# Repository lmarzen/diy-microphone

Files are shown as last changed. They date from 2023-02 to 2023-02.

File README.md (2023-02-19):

# diy-microphone

This project contributes a KiCad PCB design that implements the circuit described in the DIY Perks Microphone Project v1, https://www.youtube.com/watch?v=LoQu3XXIayc.

The PCB is designed to fit the internal form factor of the body of BM-800 XLR microphone. The BM-800 is an inexpensive microphone with a metal housing. The limited interior space of the microphone housing necessitates a dense PCB layout.

The XLR plug is replaced with a USB C female connector and a 3d printed mount is used to secure it. The SolidWorks part file and the .STL have been included as part of this repository. Additionally this 3d printable mount is used to hold the mic capsole, https://www.thingiverse.com/thing:2541735. I used a 1k reverse log potentiometer for volume control. It works and sounds great! Here are some pictures.

<p float="left">
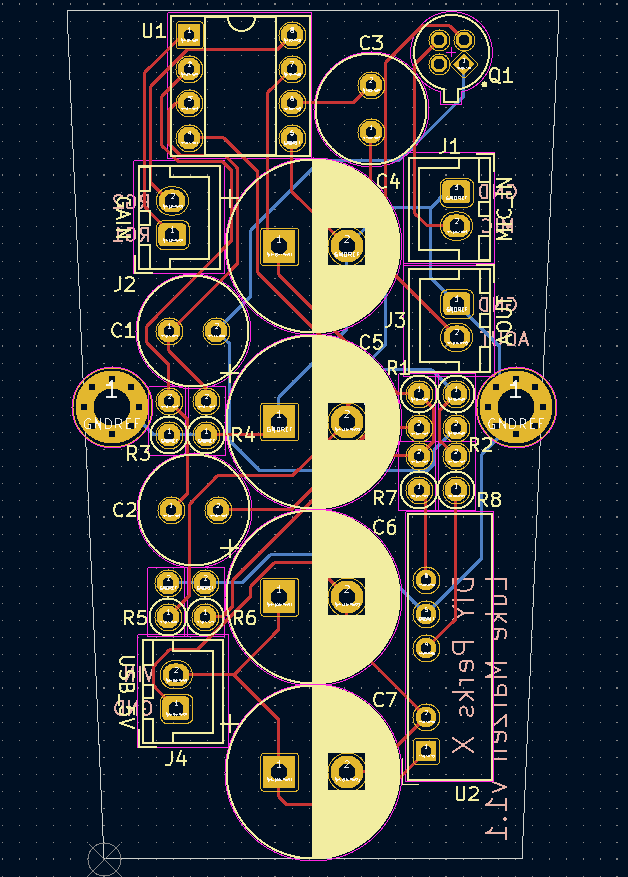
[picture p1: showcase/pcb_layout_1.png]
  
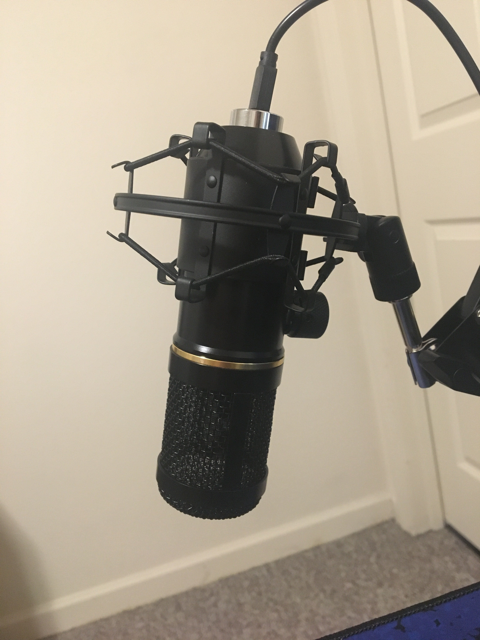
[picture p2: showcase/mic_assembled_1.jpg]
  
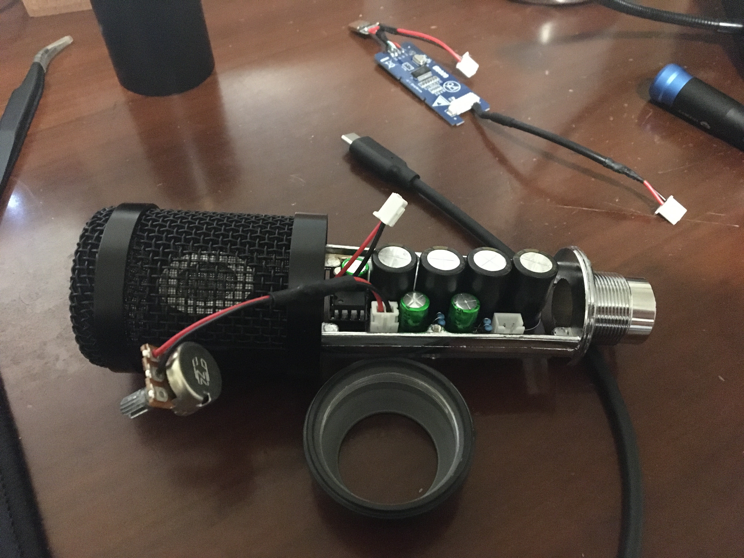
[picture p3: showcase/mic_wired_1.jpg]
  
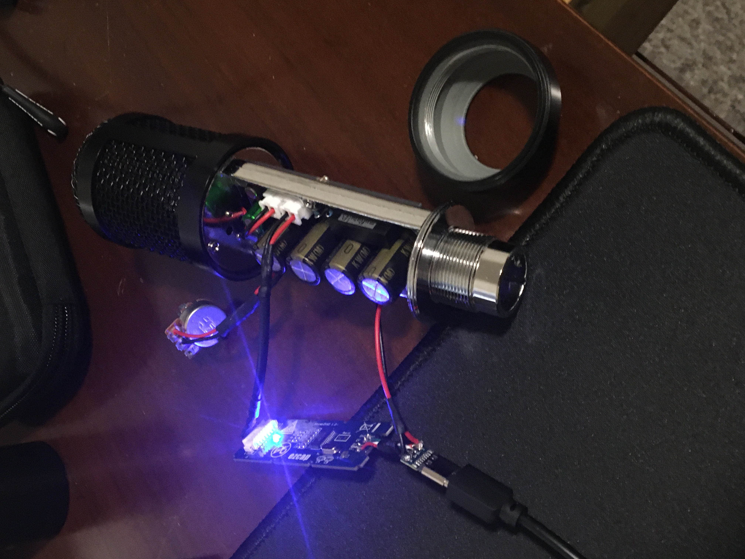
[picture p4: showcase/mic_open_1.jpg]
   
</p>

Matt (DIY Perks) has created extensive documentation for the DIY Perks Microphone Project v1 in the form of a youtube video, https://www.youtube.com/watch?v=LoQu3XXIayc. More information related to his project can be found here, https://diyperks.com/project_31_high-quality-usb-c-microphone/.

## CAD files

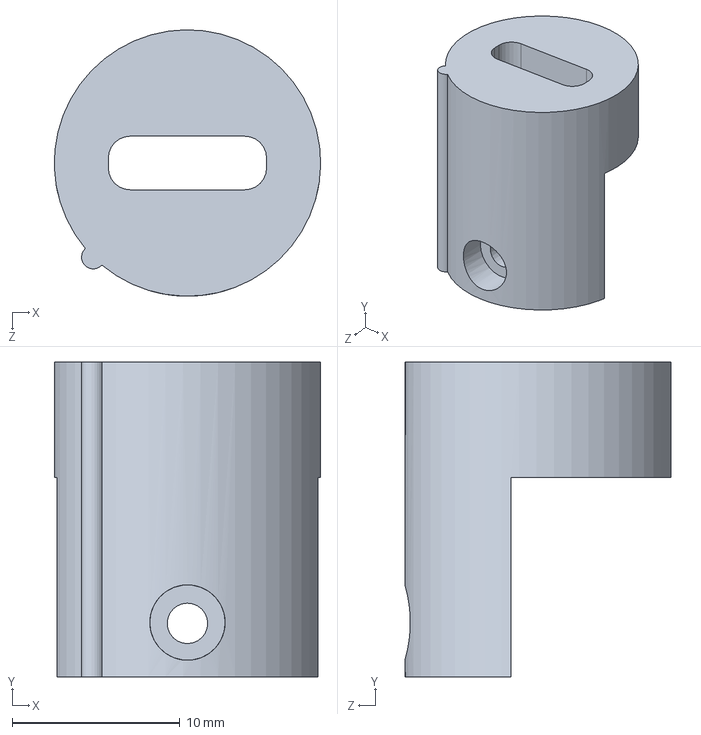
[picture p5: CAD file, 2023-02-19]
XLR_to_USB_mic.SLDPRT
15.9 x 18.8 x 15.9 mm

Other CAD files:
XLR_to_USB_mic.STL

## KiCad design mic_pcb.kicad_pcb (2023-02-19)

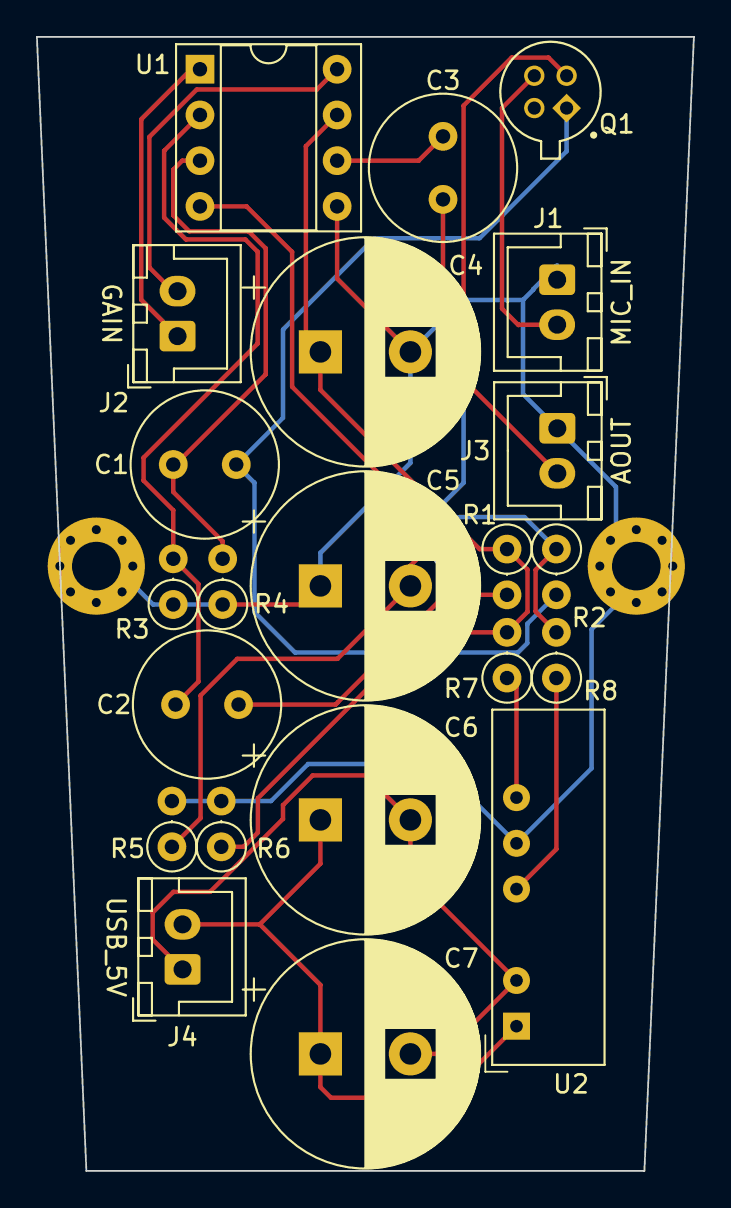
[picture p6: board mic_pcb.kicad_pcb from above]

Board: 2 copper layers, 36.5 x 63.0 mm, 22 parts (0 on the bottom side), 16 nets.

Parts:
C1, C2, C3: 22uf 35v; C_Radial_D8.0mm_H11.5mm_P3.50mm
C4, C5, C6, C7: 2200uf 16v; CP_Radial_D12.5mm_P5.00mm
J1: MIC_IN; JST_XH_B2B-XH-A_1x02_P2.50mm_Vertical
J2: GAIN; JST_XH_B2B-XH-A_1x02_P2.50mm_Vertical
J3: AUDIO_OUT; JST_XH_B2B-XH-A_1x02_P2.50mm_Vertical
J4: 5v USB; JST_XH_B2B-XH-A_1x02_P2.50mm_Vertical
Q1: 2N4416; TO127P584H533-4
R1, R2, R5, R6: 2.2k; R_Axial_DIN0207_L6.3mm_D2.5mm_P2.54mm_Vertical
R3, R4: 3.9k; R_Axial_DIN0207_L6.3mm_D2.5mm_P2.54mm_Vertical
R7, R8: 100; R_Axial_DIN0207_L6.3mm_D2.5mm_P2.54mm_Vertical
U1: THAT1512; DIP-8_W7.62mm_Socket
U2: NMA0515SC; Converter_DCDC_Murata_NMAxxxxSC_THT

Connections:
GNDREF: C4.2, C5.1, J1.1, J3.1, R3.1, R4.1, R5.2, R6.2, U1.5 (REF), U2.5 (0V)
unnamed: C1.1, R4.2, U1.3 (IN+)
unnamed: C1.2, Q1.1, R2.2
unnamed: C2.1, R3.2, U1.2 (IN-)
unnamed: C2.2, Q1.2, R1.2
unnamed: C3.1, J3.2
unnamed: C3.2, U1.6
unnamed: C4.1, R1.1, R6.1, R7.2, U1.7 (V+)
unnamed: C5.2, R2.1, R5.1, R8.2, U1.4 (V-)
unnamed: C6.1, C7.1, J4.2, U2.1 (VIN+)
unnamed: C6.2, C7.2, J4.1, U2.2 (VIN-)
unnamed: J1.2, Q1.3
unnamed: J2.1, U1.1 (RG1)
unnamed: J2.2, U1.8 (RG2)
unnamed: R7.1, U2.6 (VOUT+)
unnamed: R8.1, U2.4 (VOUT-)

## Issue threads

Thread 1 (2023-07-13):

Static on the output

mattDuque, 2023-07-13:
Hello there, dunno if you are still paying attention to this repo, but if you are could you help debug what's happening?
I ordered the pcb and assambled it, I'm using an Apple dongle DAC as my usb interface and all I get is a bunch of static, did you run into this at any point?

lmarzen, 2023-07-13:
The first time I turned it on once fully assembled I got static. The issue for me what that there was a short to the microphone body, via the potentiometer (i think). It is pretty tight to get everything in the mic body. Have you tried powering it on outside of the case?

mattDuque, 2023-07-13:
It's all open air at the minute, there is one thing that got me a little confused, the original schematic call non polar caps for the 22uf, but in your pics they look electrolytic, is that right? I used electrolytic on my build and it felt a little wrong

lmarzen, 2023-07-13:
That's probably your issue. I used non-polar electrolytic for the 22uf caps. They can be more difficult to find.

mattDuque, 2023-07-13:
I see, ok I'll try to get ahold of some of these try again, thank you

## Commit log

2023-02-19 added kicad files
    [mic_pcb.kicad_pcb, mic_pcb.kicad_sch]
2023-02-19 added 3d model files
    [XLR_to_USB_mic.SLDPRT, XLR_to_USB_mic.STL]
2023-02-19 updated pcb image
